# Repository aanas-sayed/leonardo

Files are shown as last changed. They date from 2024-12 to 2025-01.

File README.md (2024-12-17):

# Arduino Leonardo - KiCad 8 Port

This project is a fork of the original [Arduino Leonardo KiCad project](https://github.com/eltorio/leonardo). It has been modified to remove any branding restrictions, making it suitable for use in general projects without concerns about licenses or rebuilding the Bill of Materials (BOM). Footprints have been updated to use components from the KiCad standard library, allowing for the use of some of the cheapest products available on the market. These changes ensure a low-cost BOM. 

> [!NOTE] 
> This repository may not be maintained regularly. I am only doing this for a one-off project, but leaving it here in case it benefits anyone else.

## Overview

The Arduino Leonardo board design has been ported to **KiCad 8**, enabling hobbyists and developers to integrate it into their own projects easily.

## Schematic
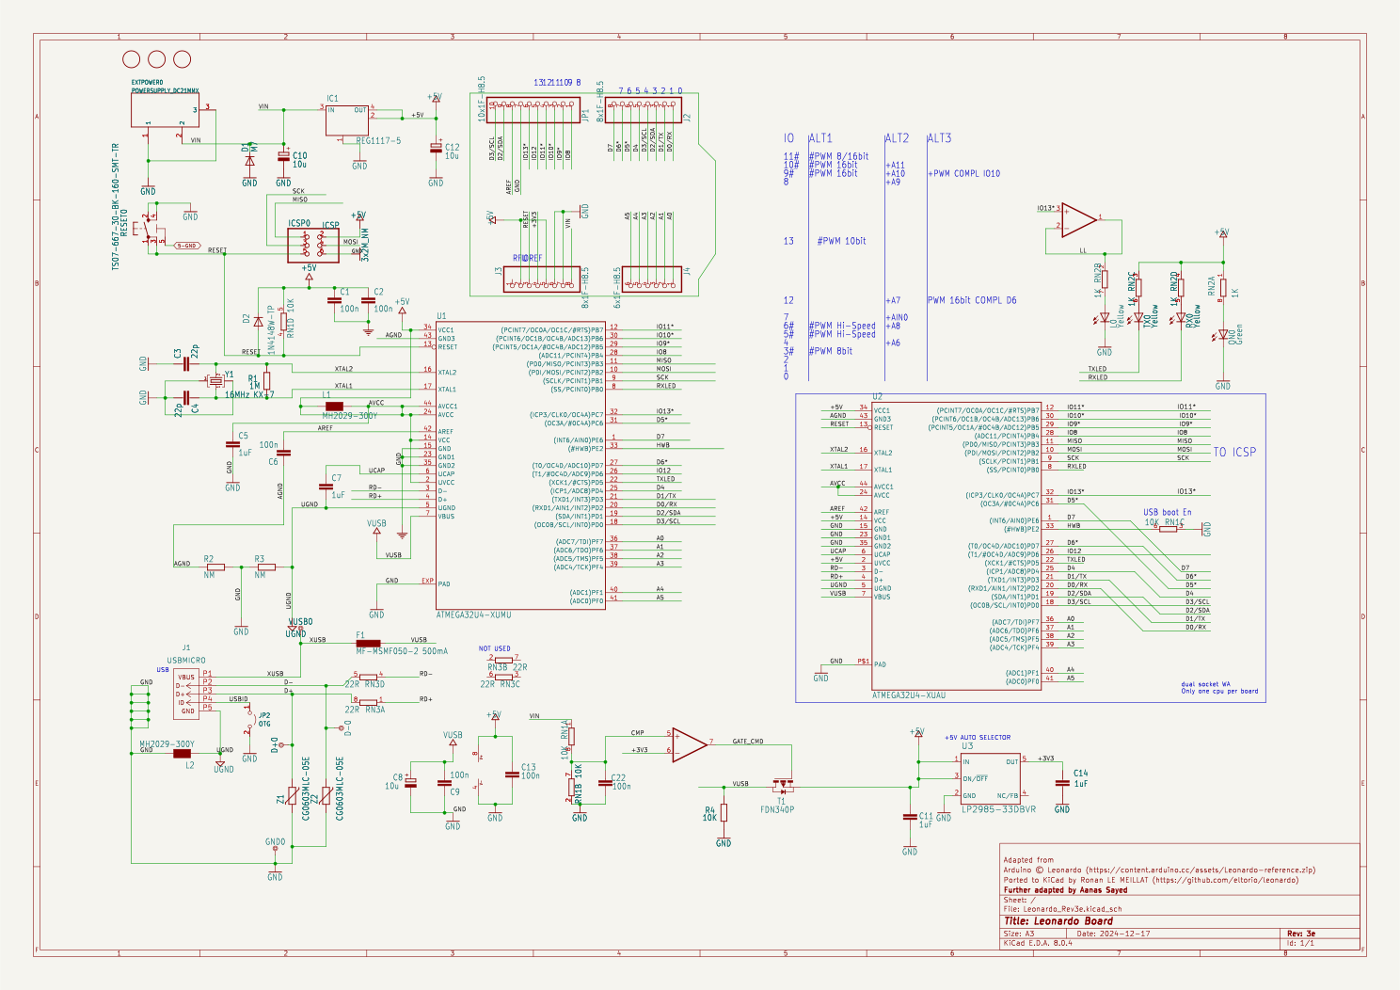
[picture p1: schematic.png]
Schematic
  
View the full [schematic PDF](https://github.com/eltorio/leonardo/raw/main/schematic.pdf).

## PCB Layout
Board  
The board layout matches the Arduino Leonardo Rev3 design.

- Default silkscreen **hides component references** for compatibility with Leonardo boards.
- Use the [Hide References Plugin](https://github.com/joelsa/kicad-hide-references-plugin) to toggle component visibility.

## 3D Renders
### Without Component References  
Front without refs

### With Component References  
Front with refs

## Bill of Materials (BOM)
The project includes a detailed, ready-to-use BOM: [View BOM](https://raw.githubusercontent.com/eltorio/leonardo/main/Leonardo_Rev3e.html).

Key details:
- All parts are readily available.
- Includes part numbers for ordering components from Digi-Key.

## License
This project is licensed under the **Attribution-ShareAlike 4.0 International** ([CC BY-SA 4.0](https://creativecommons.org/licenses/by-sa/4.0/)).  
The original design was ported to Kicad by [eltorio](https://github.com/eltorio/leonardo).

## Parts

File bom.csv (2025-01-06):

Reference | Value | Datasheet | Footprint | Qty | DNP | Vendor Part No | Manufacturer | Mfg Part No | Vendor
C1,C2,C6,C9,C13,C22 | 100n-16V | https://www.we-online.com/components/products/datasheet/885012206046.pdf | Capacitor_SMD:C_0603_1608Metric_Pad1.08x0.95mm_HandSolder | 6 |  | 710-885012206046 | WURTH ELEKTRONIK | 885012206046 | MOUSER
C3,C4 | 22p-10V | https://www.we-online.com/components/products/datasheet/885012006004.pdf | Capacitor_SMD:C_0603_1608Metric_Pad1.08x0.95mm_HandSolder | 2 |  | 710-885012006004 | WURTH ELEKTRONIK | 885012006004 | MOUSER
C5,C7,C11,C14 | 1uF-16V | https://www.we-online.com/components/products/datasheet/885012206052.pdf | Capacitor_SMD:C_0603_1608Metric_Pad1.08x0.95mm_HandSolder | 4 |  | 710-885012206052 | WURTH ELEKTRONIK | 885012206052 | MOUSER
C8,C10,C12 | 10u-16V | https://www.we-online.com/components/products/datasheet/885012208041.pdf | Capacitor_SMD:C_1206_3216Metric_Pad1.33x1.80mm_HandSolder | 3 |  | 710-885012208041 | WURTH ELEKTRONIK | 885012208041 | MOUSER
D1 | PMEG6020AELR | https://assets.nexperia.com/documents/data-sheet/PMEG6020AELR.pdf | Diode_SMD:Nexperia_CFP3_SOD-123W | 1 |  | 771-PMEG6020AELRX | NEXPERIA | PMEG6020AELRX | MOUSER
D2 | PMEG4005EH | https://assets.nexperia.com/documents/data-sheet/PMEG4005EH.pdf | Diode_SMD:D_SOD-123F | 1 |  | 771-PMEG4005EH-T/R | NEXPERIA | PMEG4005EH,115 | MOUSER
EXTPOWER0 | POWERSUPPLY_DC21MM | https://www.we-online.com/components/products/datasheet/694108301002.pdf | Leonardo_Rev3e:BarrelJack_Horizontal_Wurth_694108301002 | 1 |  | 710-694108301002 | WURTH ELEKTRONIK | 694108301002 | MOUSER
F1 | 500mA | https://www.belfuse.com/resources/datasheets/circuitprotection/ds-cp-0zcg-series.pdf | Fuse:Fuse_1812_4532Metric_Pad1.30x3.40mm_HandSolder | 1 |  | 530-0ZCG0050FF2C | BEL FUSE | 0ZCG0050FF2C | MOUSER
IC1 | LDI1117-05H | https://diotec.com/request/datasheet/ldi1117h.pdf | Package_TO_SOT_SMD:SOT-223 | 1 |  | 637-LDI1117-05H | DIOTEC SEMICONDUCTOR | LDI1117-05H | MOUSER
IC2 | LM358LVIDGKR | https://www.ti.com/lit/ds/symlink/lm358lv.pdf | Package_SO:MSOP-8_3x3mm_P0.65mm | 1 |  | 595-LM358LVIDGKR | TEXAS INSTRUMENTS | LM358LVIDGKR | MOUSER
ICSP0 | ICSP | https://www.we-online.com/components/products/datasheet/61300621121.pdf | Leonardo_Rev3e:2X03 | 1 |  | 710-61300621121 | WURTH ELEKTRONIK | 61300621121 | MOUSER
J1 | USBMICRO | https://www.we-online.com/components/products/datasheet/629105150521.pdf | Leonardo_Rev3e:Micro_USB_2.0_SMT_Type_B_Wurth_629105150521 | 1 |  | 710-629105150521 | WURTH ELEKTRONIK | 629105150521 | MOUSER
J2,J3 | 8x1F-H8.5 | https://www.we-online.com/components/products/datasheet/61300811821.pdf | Leonardo_Rev3e:1X08 | 2 |  | 710-61300811821 | WURTH ELEKTRONIK | 61300811821 | MOUSER
J4 | 6x1F-H8.5 | https://www.we-online.com/components/products/datasheet/61300611821.pdf | Leonardo_Rev3e:1X06 | 1 |  | 710-61300611821 | WURTH ELEKTRONIK | 61300611821 | MOUSER
JP1 | 10x1F-H8.5 | https://www.we-online.com/components/products/datasheet/61301011821.pdf | Leonardo_Rev3e:1X10 | 1 |  | 710-61301011821 | WURTH ELEKTRONIK | 61301011821 | MOUSER
JP2 | OTG | https://www.we-online.com/components/products/datasheet/61300211121.pdf | Leonardo_Rev3e:HEADER_2_2.54 | 1 | DNP | 710-61300211121 | WURTH ELEKTRONIK | 61300211121 | MOUSER
L0,RX0,TX0 | Yellow | https://www.we-online.com/components/products/datasheet/150080YS75000.pdf | Leonardo_Rev3e:CHIPLED_0805 | 3 |  | 710-150080YS75000 | WURTH ELEKTRONIK | 150080YS75000 | MOUSER
L1,L2 | 74279206 | https://www.we-online.com/components/products/datasheet/74279206.pdf | Resistor_SMD:R_0805_2012Metric_Pad1.20x1.40mm_HandSolder | 2 |  | 710-74279206 | WURTH ELEKTRONIK | 74279206 | MOUSER
ON0 | Green | https://www.we-online.com/components/products/datasheet/150080GS75000.pdf | Leonardo_Rev3e:CHIPLED_0805 | 1 |  | 710-150080GS75000 | WURTH ELEKTRONIK | 150080GS75000 | MOUSER
R1 | 1M | https://www.bourns.com/docs/product-datasheets/cr.pdf?sfvrsn=574d41f6_16 | Resistor_SMD:R_0603_1608Metric_Pad0.98x0.95mm_HandSolder | 1 |  | 652-CR0603FX-1004ELF | BOURNS | CR0603-FX-1004ELF | MOUSER
R2,R3 | 0 | https://www.yageo.com/upload/media/product/products/datasheet/rchip/PYu-RC_Group_51_RoHS_L_12.pdf | Resistor_SMD:R_0402_1005Metric_Pad0.72x0.64mm_HandSolder | 2 | DNP | 603-RC0603FR-070RL | YAGEO | RC0603FR-070RL | MOUSER
R4 | 10K | http://www.kamaya.co.jp/upload/products_pdf/kamaya_products(RMC1-32,RMC1-20,RMC1-16S,RMC1-16,RMC1-10,RMC1-8,RMC1-4,RMC1-2,RMC1)_english_20240824_132441.pdf | Resistor_SMD:R_0603_1608Metric_Pad0.98x0.95mm_HandSolder | 1 |  | 791-RMC1/16103JTP | KAMAYA | RMC1/16-103JTP | MOUSER
RESET0 | 431181015816 | https://www.we-online.com/components/products/datasheet/431181015816.pdf | Leonardo_Rev3e:PushButton_Wurth_431181015816 | 1 |  | 710-431181015816 | WURTH ELEKTRONIK | 431181015816 | MOUSER
RN1 | 10K | https://www.bourns.com/data/global/pdfs/CATCAY.pdf | Resistor_SMD:R_Cat16-4 | 1 |  | 652-CAY16-1002F4LF | BOURNS | CAY16-1002F4LF | MOUSER
RN2 | 1K | https://www.bourns.com/data/global/pdfs/CATCAY.pdf | Resistor_SMD:R_Cat16-4 | 1 |  | 652-CAY16-1001F4LF | BOURNS | CAY16-1001F4LF | MOUSER
RN3 | 22R | https://www.bourns.com/data/global/pdfs/CATCAY.pdf | Resistor_SMD:R_Cat16-4 | 1 |  | 652-CAY16-22R0F4LF | BOURNS | CAY16-22R0F4LF | MOUSER
T1 | NXV65UP | https://assets.nexperia.com/documents/data-sheet/NXV65UP.pdf | Package_TO_SOT_SMD:SOT-23 | 1 |  | 771-NXV65UPR | NEXPERIA | NXV65UPR | MOUSER
U1 | ATMEGA32U4-MU | https://ww1.microchip.com/downloads/en/DeviceDoc/Atmel-7766-8-bit-AVR-ATmega16U4-32U4_Datasheet.pdf | Leonardo_Rev3e:QFN44ML7X7 | 1 |  | 556-ATMEGA32U4-MU | MICROCHIP TECHNOLOGY | ATMEGA32U4-MU | MOUSER
U2 | ATMEGA32U4-AU | https://ww1.microchip.com/downloads/en/DeviceDoc/Atmel-7766-8-bit-AVR-ATmega16U4-32U4_Datasheet.pdf | Leonardo_Rev3e:TQFP44-PAD | 1 | DNP | 556-ATMEGA32U4-AU | MICROCHIP TECHNOLOGY | ATMEGA32U4-AU | MOUSER
U3 | LDI559-3.3EN | https://diotec.com/request/datasheet/ldi559en.pdf | Package_TO_SOT_SMD:SOT-23-5 | 1 |  | 637-LDI559-3.3EN | DIOTEC SEMICONDUCTOR | LDI559-3.3EN | MOUSER
Y1 | 16MHz | https://www.geyer-electronic.shop/downloads/products/1288722/12.88722.pdf | Leonardo_Rev3e:CRYSTAL-3.2-2.5 | 1 |  | 4983-12.88722CT-ND | GEYER ELECTRONIC AMERICA, INC. | 12.88722 | DIGIKEY
Z1,Z2 | 82306050029 | https://www.we-online.com/components/products/datasheet/82306050029.pdf | Resistor_SMD:R_0603_1608Metric_Pad0.98x0.95mm_HandSolder | 2 |  | 710-82306050029 | WURTH ELEKTRONIK | 82306050029 | MOUSER

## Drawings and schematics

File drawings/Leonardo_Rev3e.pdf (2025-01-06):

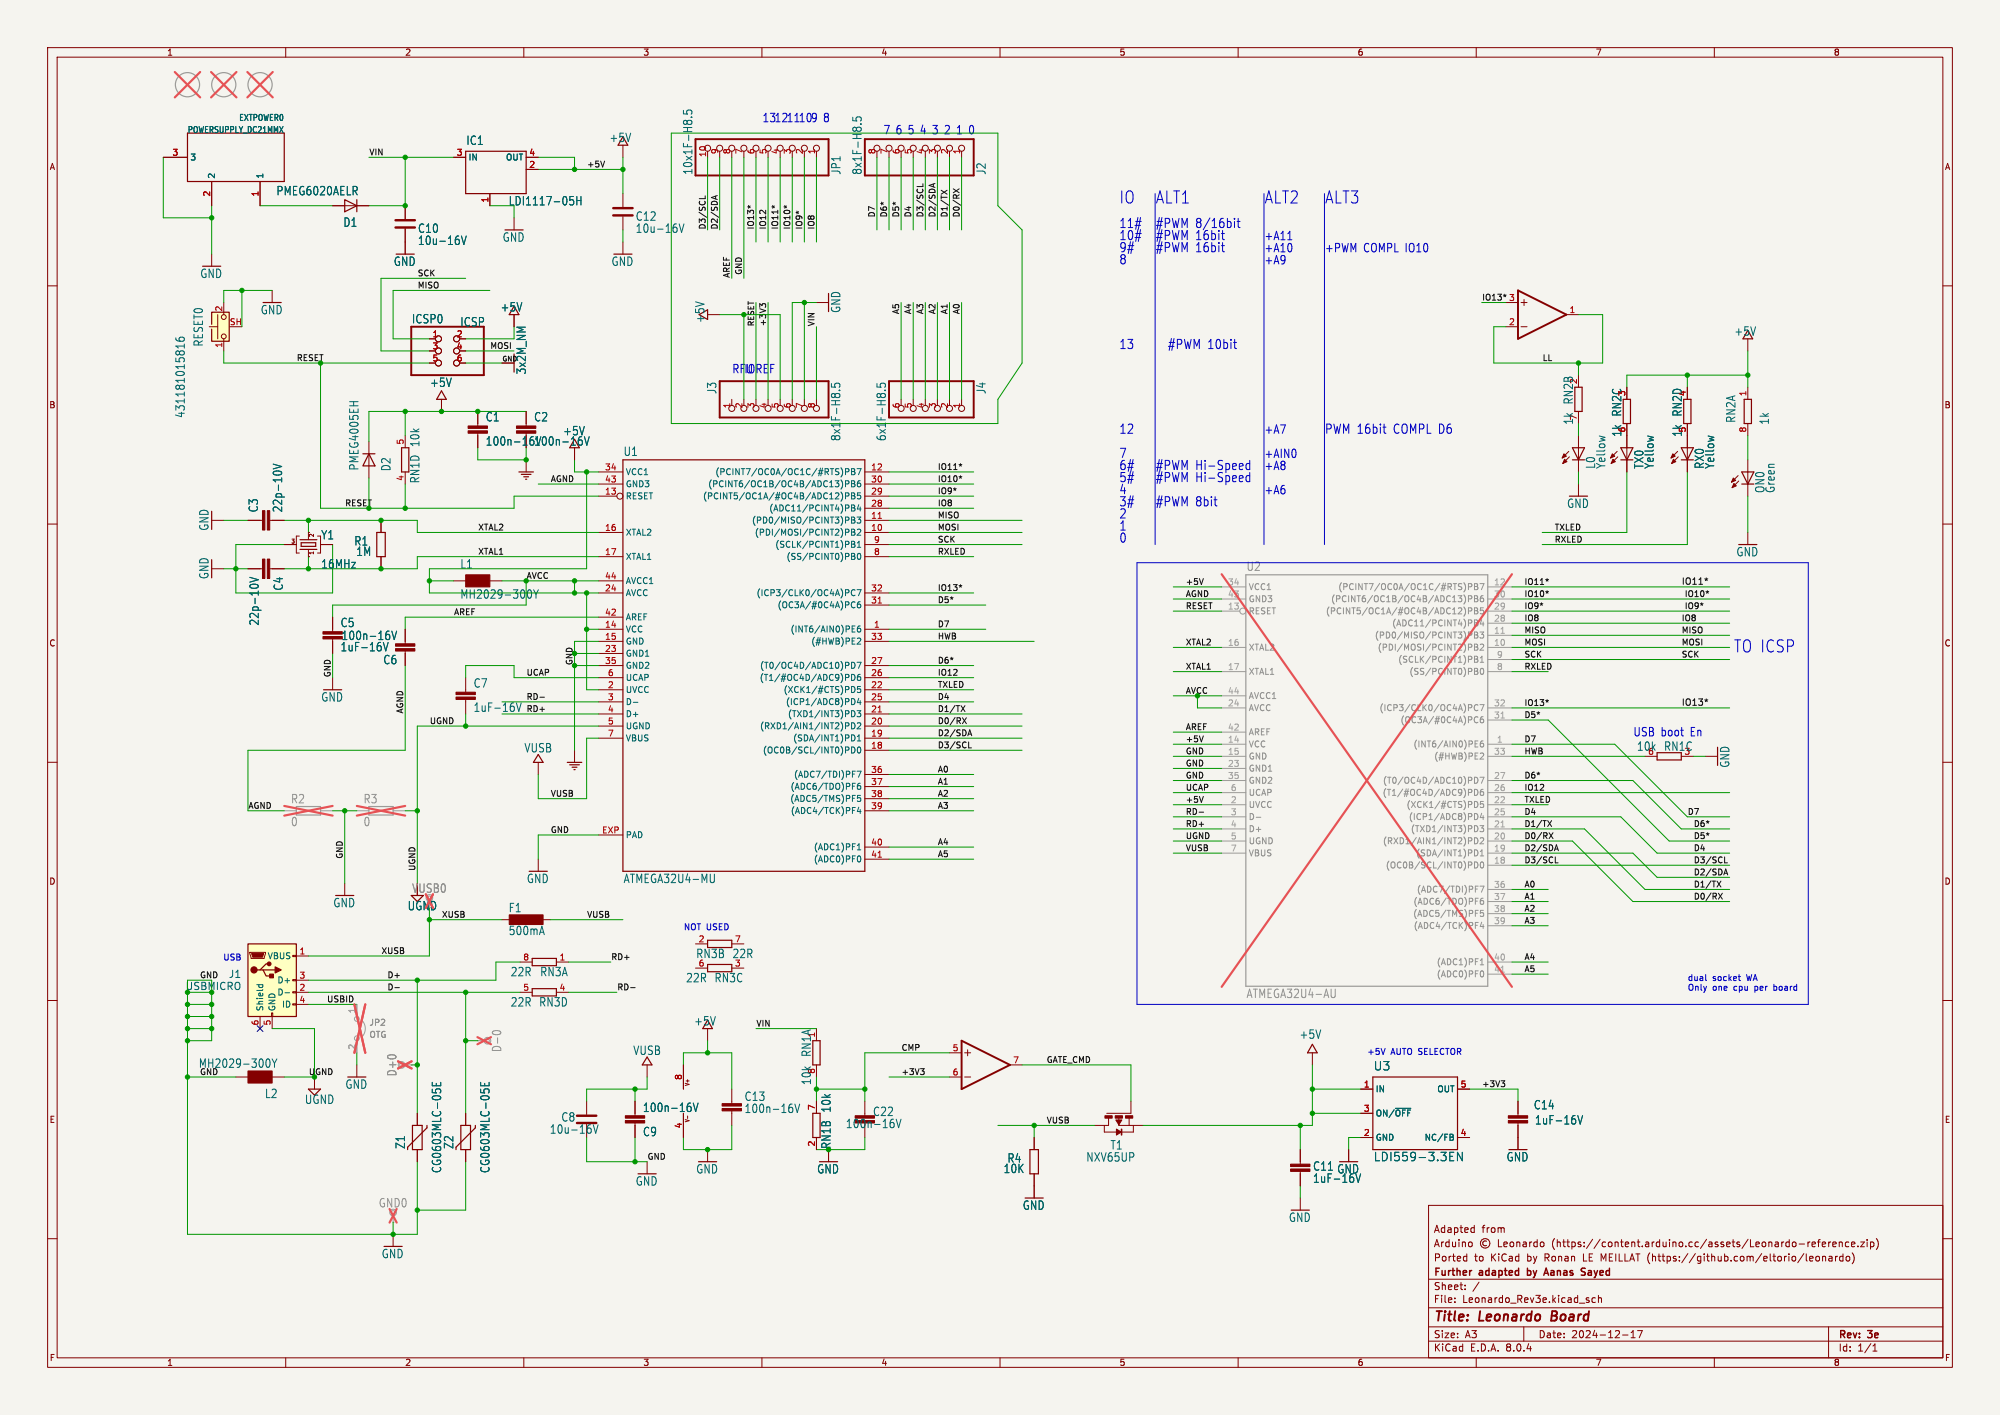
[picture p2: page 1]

IO9* SCK MISO D3/SCL D2/SDA

Id: 1/1 Title: Leonardo Board

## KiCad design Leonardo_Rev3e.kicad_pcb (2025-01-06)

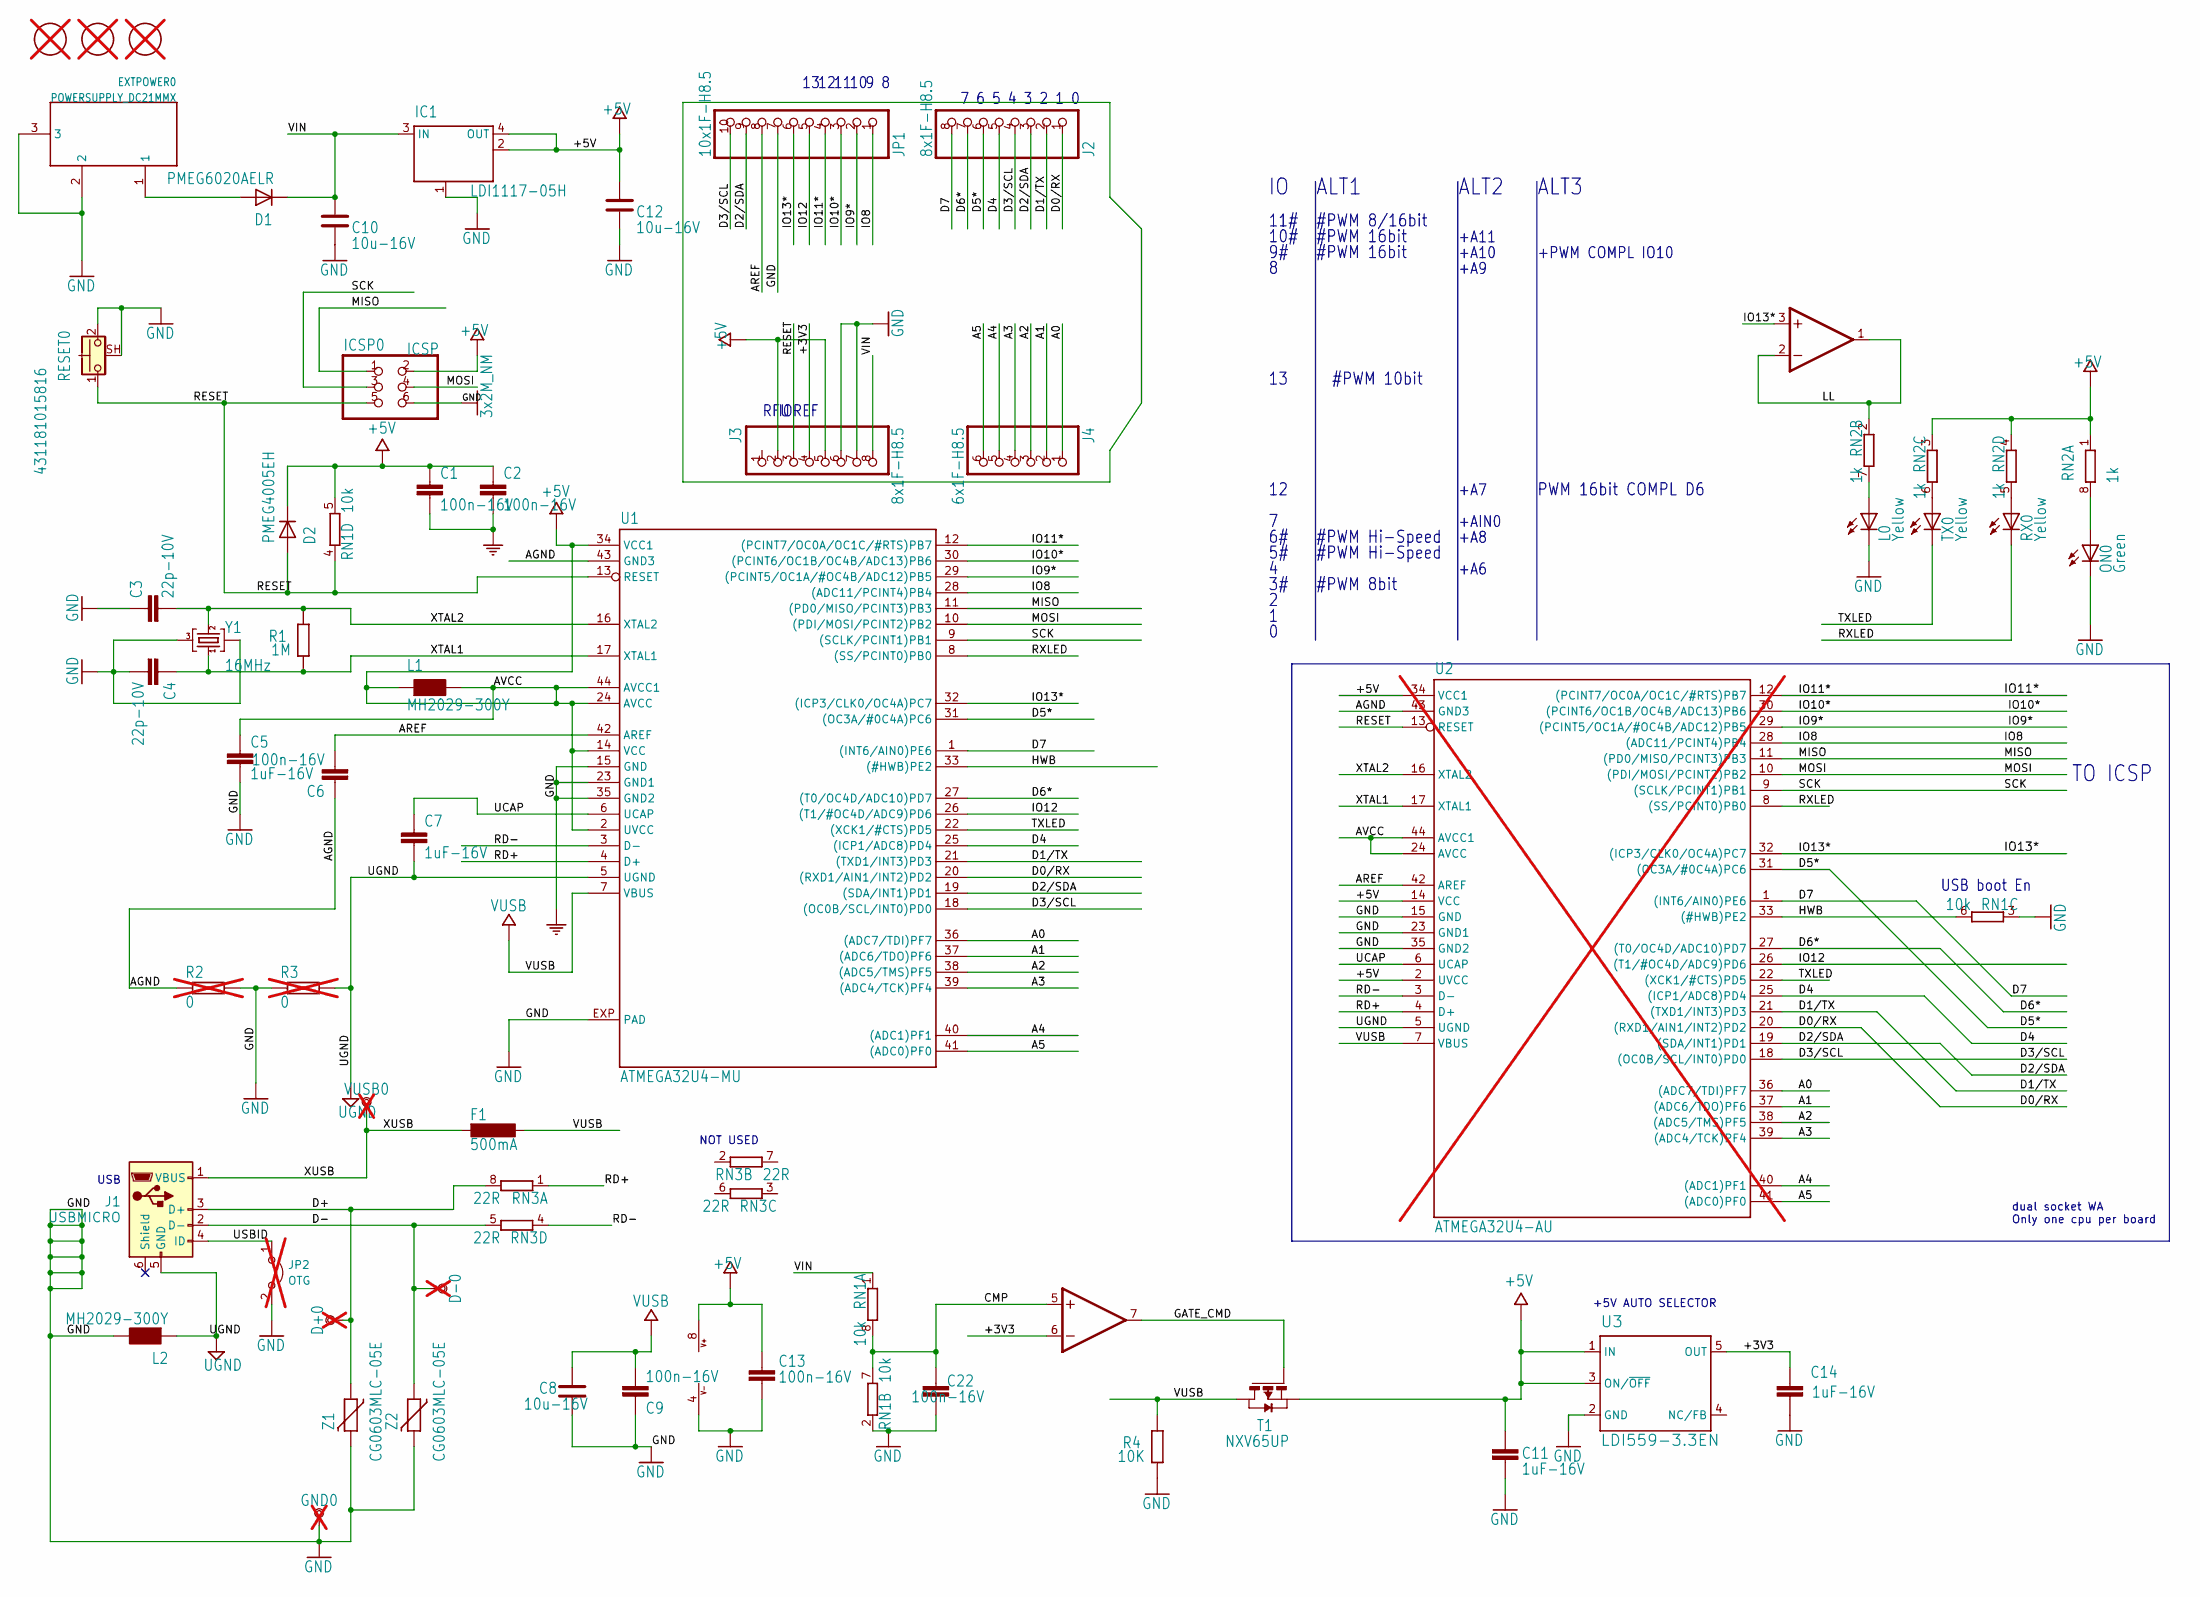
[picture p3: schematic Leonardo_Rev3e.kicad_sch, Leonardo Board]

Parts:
C1, C2, C6, C9, C13, C22: 100n-16V; C_0603_1608Metric_Pad1.08x0.95mm_HandSolder; Mfg Part No 885012206046
C3, C4: 22p-10V; C_0603_1608Metric_Pad1.08x0.95mm_HandSolder; Mfg Part No 885012006004
C5, C7, C11, C14: 1uF-16V; C_0603_1608Metric_Pad1.08x0.95mm_HandSolder; Mfg Part No 885012206052
C8, C10, C12: 10u-16V; C_1206_3216Metric_Pad1.33x1.80mm_HandSolder; Mfg Part No 885012208041
D1: PMEG6020AELR; Nexperia_CFP3_SOD-123W; Mfg Part No PMEG6020AELRX
D2: PMEG4005EH; D_SOD-123F; Mfg Part No PMEG4005EH,115
D+0: DNP; TP-1.00MM; not fitted
D-0: DNP; TP-1.00MM; not fitted
EXTPOWER0: POWERSUPPLY_DC21MMX; BarrelJack_Horizontal_Wurth_694108301002; Mfg Part No 694108301002
F1: 500mA; Fuse_1812_4532Metric_Pad1.30x3.40mm_HandSolder; Mfg Part No 0ZCG0050FF2C
FID1, FID2, FID3: DNP; FD-1-1.5; not fitted
GND0: DNP; TP-1.00MM; not fitted
IC1: LDI1117-05H; SOT-223; Mfg Part No LDI1117-05H
IC2: LM358LVIDGKR; MSOP-8_3x3mm_P0.65mm; Mfg Part No LM358LVIDGKR
ICSP0: ICSP; 2X03; Mfg Part No 61300621121
J1: USBMICRO; Micro_USB_2.0_SMT_Type_B_Wurth_629105150521; Mfg Part No 629105150521
J2, J3: 8x1F-H8.5; 1X08; Mfg Part No 61300811821
J4: 6x1F-H8.5; 1X06; Mfg Part No 61300611821
JP1: 10x1F-H8.5; 1X10; Mfg Part No 61301011821
JP2: OTG; HEADER_2_2.54; Mfg Part No 61300211121; not fitted
L0: Yellow; CHIPLED_0805; Mfg Part No 150080YS75000
L1, L2: MH2029-300Y; R_0805_2012Metric_Pad1.20x1.40mm_HandSolder; Mfg Part No 74279206
ON0: Green; CHIPLED_0805; Mfg Part No 150080GS75000
R1: 1M; R_0603_1608Metric_Pad0.98x0.95mm_HandSolder; Mfg Part No CR0603-FX-1004ELF
R2, R3: 0; R_0402_1005Metric_Pad0.72x0.64mm_HandSolder; Mfg Part No RC0603FR-070RL; not fitted
R4: 10K; R_0603_1608Metric_Pad0.98x0.95mm_HandSolder; Mfg Part No RMC1/16-103JTP
RESET0: 431181015816; PushButton_Wurth_431181015816; Mfg Part No 431181015816
RN1: 10k; R_Cat16-4; Mfg Part No CAY16-1002F4LF
RN2: 1k; R_Cat16-4; Mfg Part No CAY16-1001F4LF
RN3: 22R; R_Cat16-4; Mfg Part No CAY16-22R0F4LF
RX0: Yellow; CHIPLED_0805; Mfg Part No 150080YS75000
T1: NXV65UP; SOT-23; Mfg Part No NXV65UPR
TX0: Yellow; CHIPLED_0805; Mfg Part No 150080YS75000
U1: ATMEGA32U4-MU; QFN44ML7X7; Mfg Part No ATMEGA32U4-MU
U2: ATMEGA32U4-AU; TQFP44-PAD; Mfg Part No ATMEGA32U4-AU; not fitted
U3: LDI559-3.3EN; SOT-23-5; Mfg Part No LDI559-3.3EN
VUSB0: DNP; TP-1.00MM; not fitted
Y1: 16MHz; CRYSTAL-3.2-2.5; Mfg Part No 12.88722
Z1, Z2: CG0603MLC-05E; R_0603_1608Metric_Pad0.98x0.95mm_HandSolder; Mfg Part No 82306050029

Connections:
3x2M_NM: C1.2, C2.2, C3.1, C4.2, C5.2, C8.2, C9.1, C10.2, C11.1, C12.2, C13.2, C14.1, C22.1, EXTPOWER0.2, EXTPOWER0.3, GND0.X, IC1.1 (GND/ADJ), IC2.4 (V-), ICSP0.6, J3.6, J3.7, JP1.7, JP2.2 (B), L0.C, L2.2, ON0.C, R2.2, R3.1, R4.1, RESET0.2, RESET0.SH (B), RN1.2 (1), RN1.3 (1), U1.15 (GND), U1.23 (GND1), U1.35 (GND2), U1.EXP (PAD), U2.15 (GND), U2.23 (GND1), U2.35 (GND2), U3.2 (GND), Y1.2 (GND@1), Y1.4 (GND@2), Z1.2, Z2.2
+5V: C1.1, C2.1, C5.1, C11.2, C12.1, C13.1, D2.1 (K), IC1.2 (OUT@1), IC1.4 (OUT), IC2.8 (V+), ICSP0.2, J3.2, J3.5, L1.1, L1.2, RN1.5 (2), RN2.1, RN2.3 (1), RN2.4 (1), T1.2 (S), U1.2 (UVCC), U1.14 (VCC), U1.24 (AVCC), U1.34 (VCC1), U1.44 (AVCC1), U2.2 (UVCC), U2.14 (VCC), U2.24 (AVCC), U2.34 (VCC1), U2.44 (AVCC1), U3.1 (IN), U3.3 (ON/~OFF)
/+3V3: C14.2, IC2.6 (-IN), J3.4, U3.5 (OUT)
/A0: J4.1, U1.36 ((ADC7/TDI)PF7), U2.36 ((ADC7/TDI)PF7)
/A1: J4.2, U1.37 ((ADC6/TDO)PF6), U2.37 ((ADC6/TDO)PF6)
/A2: J4.3, U1.38 ((ADC5/TMS)PF5), U2.38 ((ADC5/TMS)PF5)
/A3: J4.4, U1.39 ((ADC4/TCK)PF4), U2.39 ((ADC4/TCK)PF4)
/A4: J4.5, U1.40 ((ADC1)PF1), U2.40 ((ADC1)PF1)
/A5: J4.6, U1.41 ((ADC0)PF0), U2.41 ((ADC0)PF0)
/AGND: C6.1, R2.1, U1.43 (GND3), U2.43 (GND3)
/AREF: C6.2, JP1.8, U1.42 (AREF), U2.42 (AREF)
/CMP: C22.2, IC2.5 (+IN), RN1.7 (2), RN1.8 (2)
/D0/RX: J2.1, U1.20 ((RXD1/AIN1/INT2)PD2), U2.20 ((RXD1/AIN1/INT2)PD2)
/D1/TX: J2.2, U1.21 ((TXD1/INT3)PD3), U2.21 ((TXD1/INT3)PD3)
/D2/SDA: J2.3, JP1.9, U1.19 ((SDA/INT1)PD1), U2.19 ((SDA/INT1)PD1)
/D3/SCL: J2.4, JP1.10, U1.18 ((OC0B/SCL/INT0)PD0), U2.18 ((OC0B/SCL/INT0)PD0)
/D4: J2.5, U1.25 ((ICP1/ADC8)PD4), U2.25 ((ICP1/ADC8)PD4)
/D5*: J2.6, U1.31 ((OC3A/#0C4A)PC6), U2.31 ((OC3A/#0C4A)PC6)
/D6*: J2.7, U1.27 ((T0/OC4D/ADC10)PD7), U2.27 ((T0/OC4D/ADC10)PD7)
/D7: J2.8, U1.1 ((INT6/AIN0)PE6), U2.1 ((INT6/AIN0)PE6)
/D+: D+0.X, J1.3 (D+), RN3.8 (2), Z1.1
/D-: D-0.X, J1.2 (D-), RN3.5 (2), Z2.1
/GATE_CMD: IC2.7 (OUT), T1.1 (G)
/HWB: RN1.6 (2), U1.33 ((#HWB)PE2), U2.33 ((#HWB)PE2)
/IO8: JP1.1, U1.28 ((ADC11/PCINT4)PB4), U2.28 ((ADC11/PCINT4)PB4)
/IO9*: JP1.2, U1.29 ((PCINT5/OC1A/#OC4B/ADC12)PB5), U2.29 ((PCINT5/OC1A/#OC4B/ADC12)PB5)
/IO10*: JP1.3, U1.30 ((PCINT6/OC1B/OC4B/ADC13)PB6), U2.30 ((PCINT6/OC1B/OC4B/ADC13)PB6)
/IO11*: JP1.4, U1.12 ((PCINT7/OC0A/OC1C/#RTS)PB7), U2.12 ((PCINT7/OC0A/OC1C/#RTS)PB7)
/IO12: JP1.5, U1.26 ((T1/#OC4D/ADC9)PD6), U2.26 ((T1/#OC4D/ADC9)PD6)
/IO13*: IC2.3 (+IN), JP1.6, U1.32 ((ICP3/CLK0/OC4A)PC7), U2.32 ((ICP3/CLK0/OC4A)PC7)
/LL: IC2.1 (OUT), IC2.2 (-IN), RN2.2 (1)
/MISO: ICSP0.1, U1.11 ((PD0/MISO/PCINT3)PB3), U2.11 ((PD0/MISO/PCINT3)PB3)
/MOSI: ICSP0.4, U1.10 ((PDI/MOSI/PCINT2)PB2), U2.10 ((PDI/MOSI/PCINT2)PB2)
/RD+: RN3.1, U1.4 (D+), U2.4 (D+)
/RD-: RN3.4 (1), U1.3 (D-), U2.3 (D-)
/RESET: D2.2 (A), ICSP0.5, J3.3, RESET0.1, RN1.4 (1), U1.13 (RESET), U2.13 (RESET)
/RXLED: RX0.C, U1.8 ((SS/PCINT0)PB0), U2.8 ((SS/PCINT0)PB0)
/SCK: ICSP0.3, U1.9 ((SCLK/PCINT1)PB1), U2.9 ((SCLK/PCINT1)PB1)
/TXLED: TX0.C, U1.22 ((XCK1/#CTS)PD5), U2.22 ((XCK1/#CTS)PD5)
/UCAP: C7.1, U1.6 (UCAP), U2.6 (UCAP)
/USBID: J1.4 (ID), JP2.1 (A)
/VIN: C10.1, D1.1 (K), IC1.3 (IN), J3.8, RN1.1
/XTAL1: C4.1, R1.1, U1.17 (XTAL1), U2.17 (XTAL1), Y1.1 (C1)
/XTAL2: C3.2, R1.2, U1.16 (XTAL2), U2.16 (XTAL2), Y1.3 (C2)
/XUSB: F1.2, J1.1 (VBUS), VUSB0.X
unnamed: D1.2 (A), EXTPOWER0.1
unnamed: ON0.A, RN2.8 (2)
unnamed: L0.A, RN2.7 (2)
unnamed: RN2.6 (2), TX0.A
unnamed: RN2.5 (2), RX0.A
UGND: C7.2, J1.5 (GND), L2.1, R3.2, U1.5 (UGND), U2.5 (UGND)
VUSB: C8.1, C9.2, F1.1, R4.2, T1.3 (D), U1.7 (VBUS), U2.7 (VBUS)

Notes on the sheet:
#PWM 8/16bit
PWM 16bit COMPL D6
USB boot En
NOT USED
RFU
#PWM 8bit
+PWM COMPL IO10
#PWM 16bit
TO ICSP
dual socket WA Only one cpu per board
#PWM Hi-Speed
+A10
11#
IOREF
+5V AUTO SELECTOR
+AIN0
ALT3
+A8
+A9
ALT1
+A6
#PWM 10bit
USB
ALT2
10#
+A11
+A7

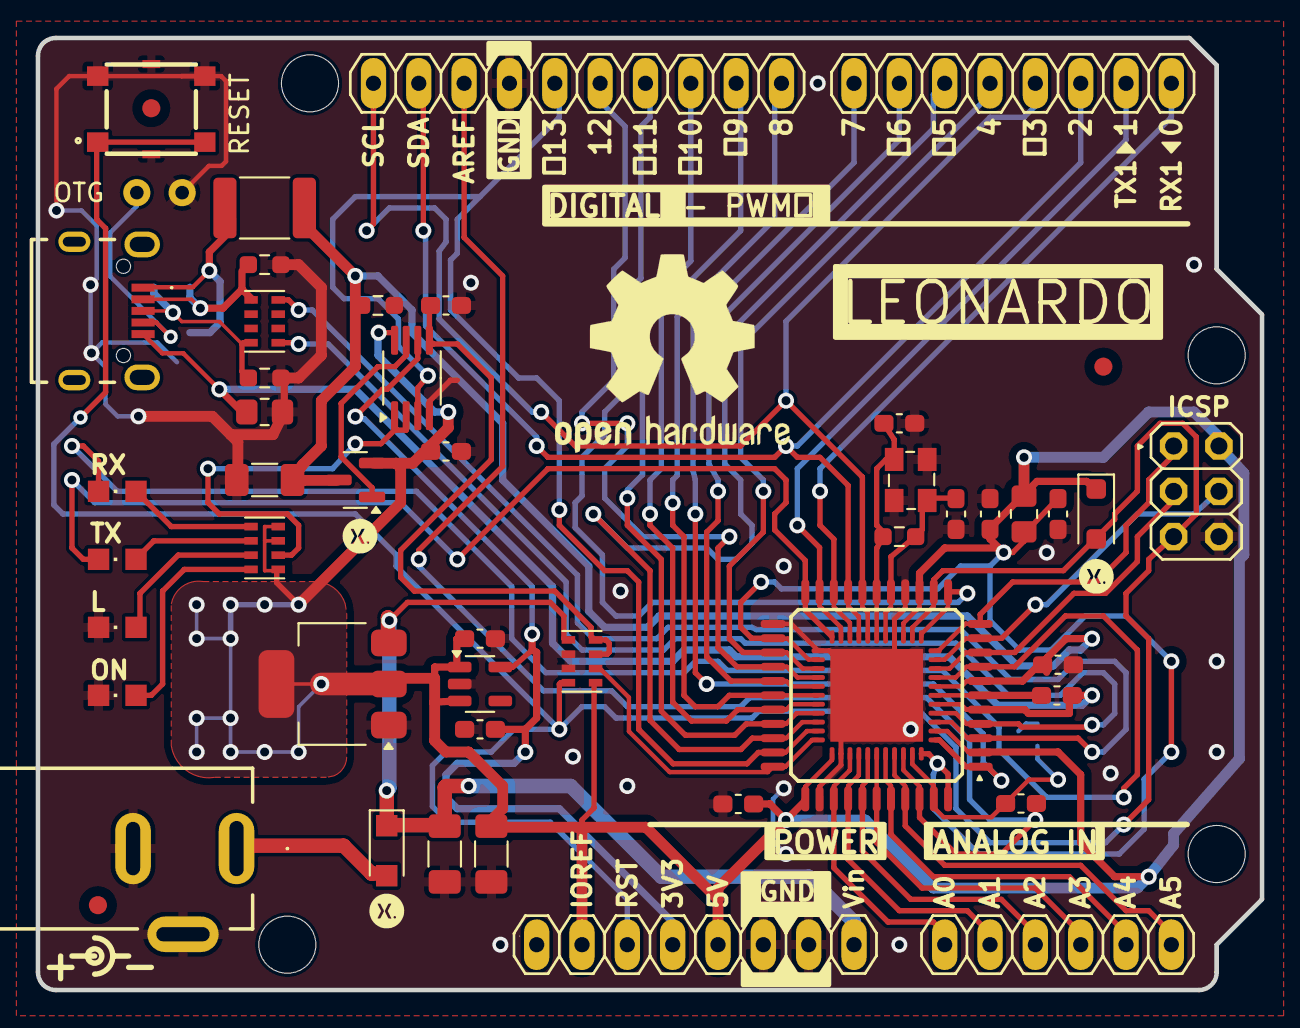
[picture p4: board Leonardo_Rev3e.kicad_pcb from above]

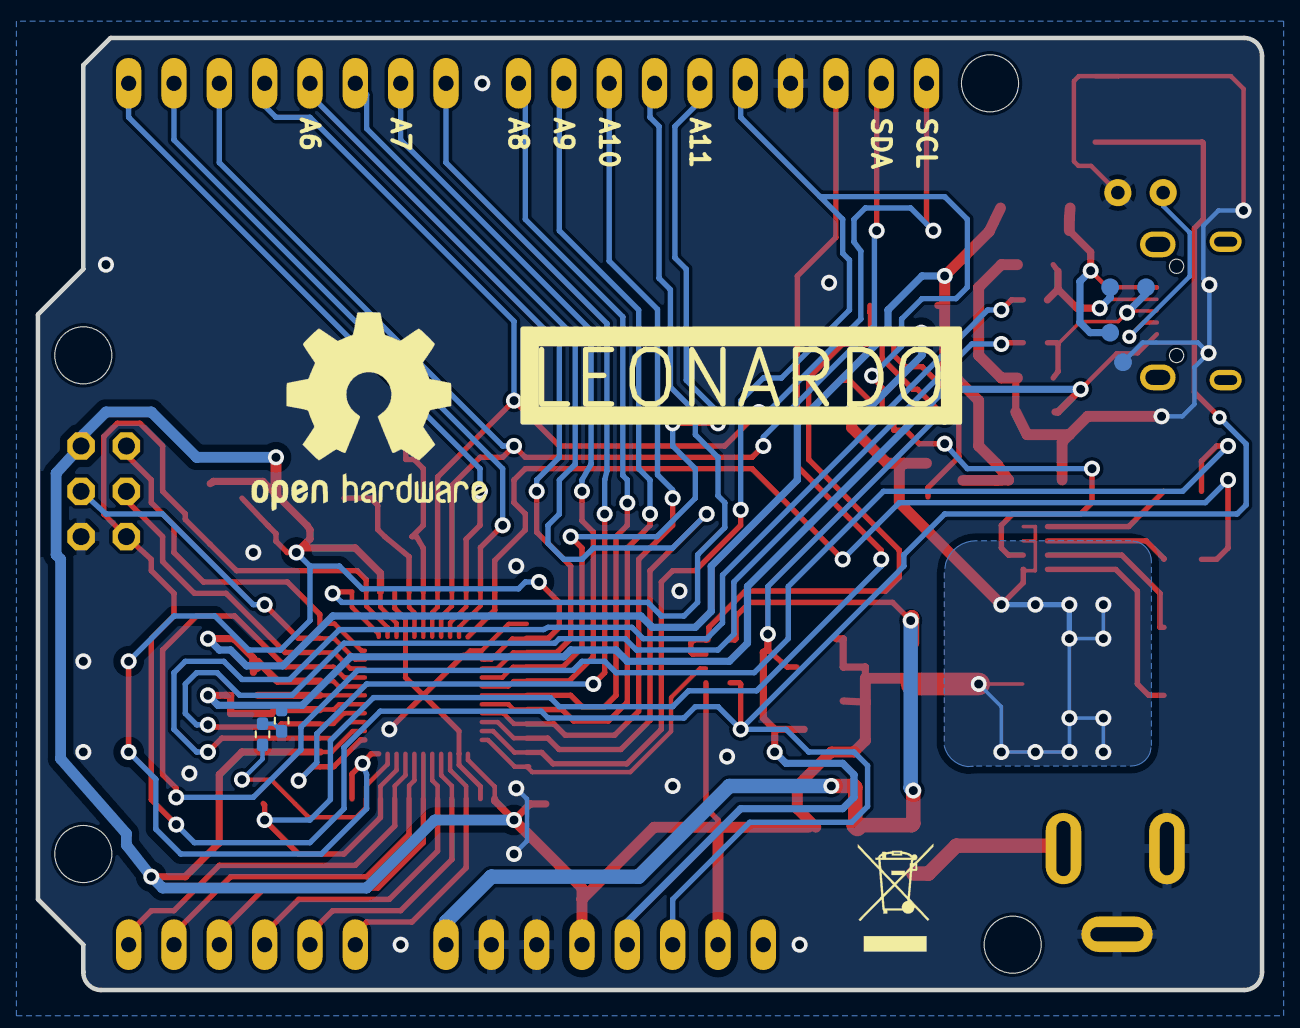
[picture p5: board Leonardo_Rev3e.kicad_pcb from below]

Board: 2 copper layers, 68.6 x 53.3 mm, 60 parts (3 on the bottom side), 52 nets.

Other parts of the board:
@HOLE0, @HOLE1, @HOLE2, @HOLE3: (no value)

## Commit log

2024-12-17 chore: adapt for forked repo
    [Leonardo_Rev3e-B_Cu.gbl, Leonardo_Rev3e-B_Mask.gbs, Leonardo_Rev3e-B_Paste.gbp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]
2024-12-23 chore: clean up footprints
    [Leonardo_Rev3e.kicad_pcb, Leonardo_Rev3e.kicad_sch]
2025-01-06 feat: use def. sym/foot and customised BOM and silkscreen
    [Leonardo_Rev3e.kicad_pcb, Leonardo_Rev3e.kicad_sch]
2025-01-06 chore: add exported bom
    [bom.csv]
2025-01-06 chore: update bom
    [Leonardo_Rev3e.kicad_pcb, Leonardo_Rev3e.kicad_sch, bom.csv]
2025-01-06 chore: update schematic export
2025-01-07 chore: sort bom columns
2025-01-07 chore: remove trailing whitespaces in BOM
    [Leonardo_Rev3e.kicad_sch]

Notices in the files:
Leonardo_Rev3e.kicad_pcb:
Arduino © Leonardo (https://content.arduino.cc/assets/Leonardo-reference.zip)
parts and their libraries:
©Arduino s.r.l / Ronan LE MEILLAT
